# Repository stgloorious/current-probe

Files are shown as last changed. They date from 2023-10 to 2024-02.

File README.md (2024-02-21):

# Low-Noise Amplifier for Current Sensing

This is an experimental breakout board for the ultralow noise AD8331
variable-gain amplifier with internal low-noise preamplifier. 

- AC-coupled input up to 200 mV
- Adjustable gain amplifier, up to 55 dB
- Galvanically isolated output
- Single 3.3V supply

The input impedance of the amplifier should be around 6k ohms.
The probe is designed to be in close proximity (< 10 mm) to the signal source,
i.e., such that no shielded cable is required on the input side.
Instead, short wires can directly be soldered to the probe.
The output is matched to 50 ohms over an isolating signal transformer, which
connects to the SMA connector.

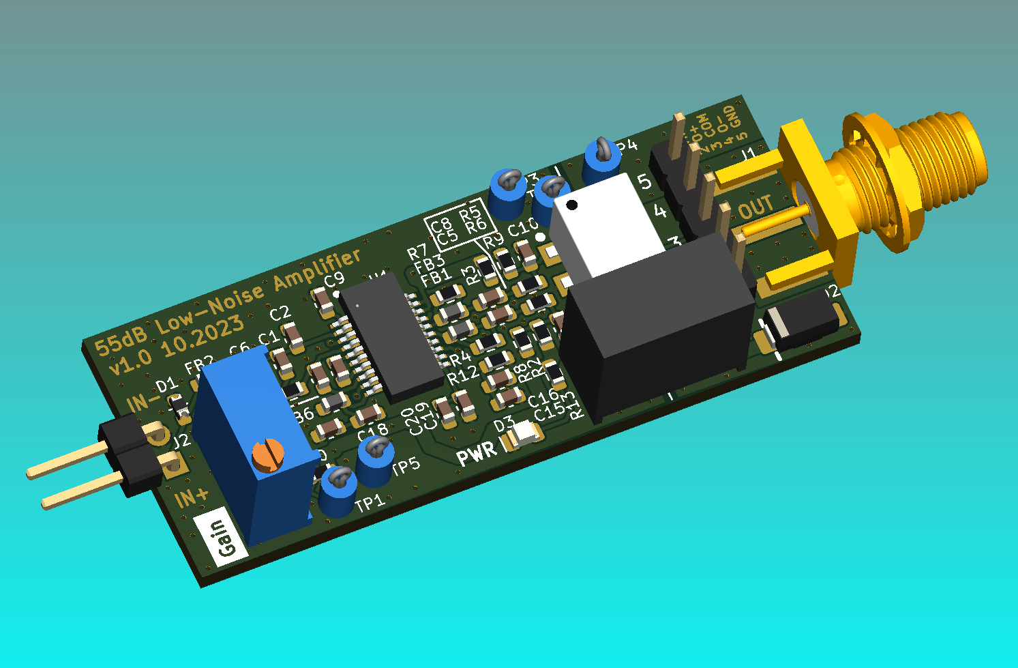
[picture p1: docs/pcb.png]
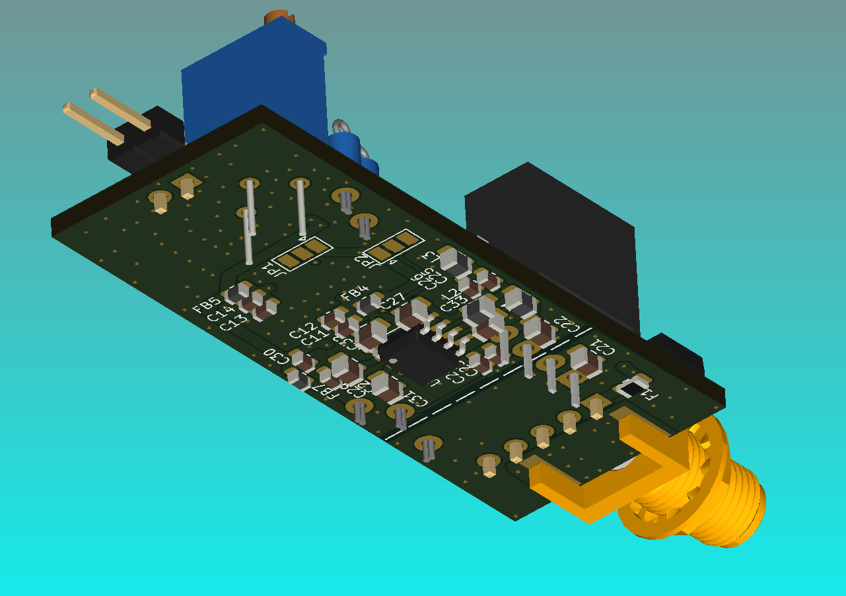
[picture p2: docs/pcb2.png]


The amplifier module is intended to be used as a current probe with
an additional shunt resistor. The amplifier is placed near the device 
under test and amplifies the voltage drop across the measurement resistor.
The output signal is digitized by an oscilloscope connected over the SMA connector.

## Progress

- [x] Schematics design
- [x] PCB layout
- [x] PCB prototype manufacturing
- [x] In-circuit verification
- [ ] Proof-of-concept of power analysis side channel attack

### Known Issues
Although there is a notch filter to suppress the parasitic switching frequency
of the DC/DC converter, it is still visible at the output.

## Motivation
The current probe is designed to measure the transient current consumption
of microcontrollers and low-end CPUs in order to use a power consumption
side channel, which can be used to leak information about cryptographic
operations.
An example power trace measured with this current probe can be seen below.
Clearly visible are the 10 AES rounds of the AES-128-ECB algorithm running
on an STM32 microcontroller.

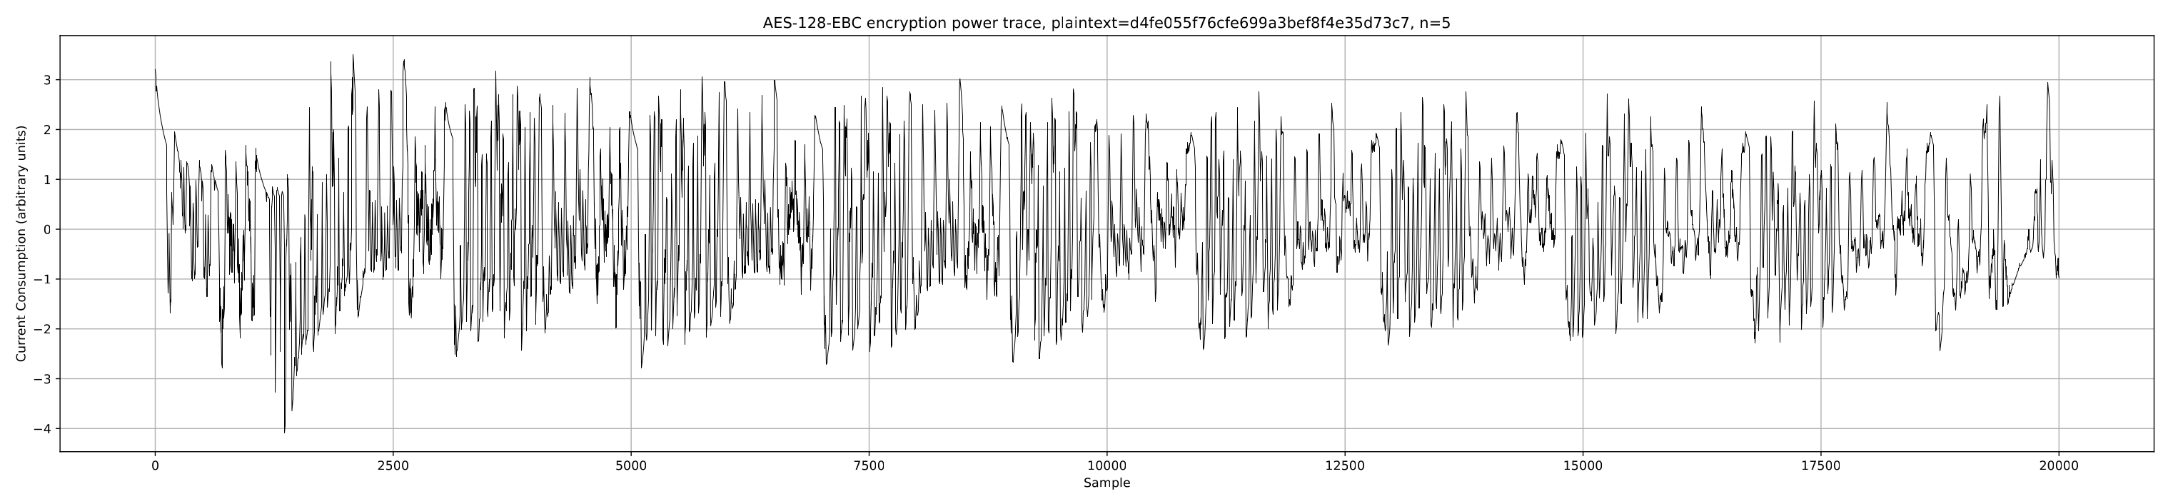
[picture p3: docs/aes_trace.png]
AES power trace


Such side-channel attacks have been known to exists for many years, and there
are even [commercial tools](https://chipwhisperer.readthedocs.io/en/latest/getting-started.html)
available which simplify the research process.

My goal with this DIY low-noise current probe is to have a cost-effective 
alternative to other specialized tools, as I already own 
suitable measurements equipment (i.e., an oscilloscope) 
and do not need access to other attack methods (such as fault injection).

## Manufacturing
PCB manufacturing was done in a custom panel with 5 individual PCBs by
[multi-cb](https://multi-cb.eu). Assembly was done by hand.

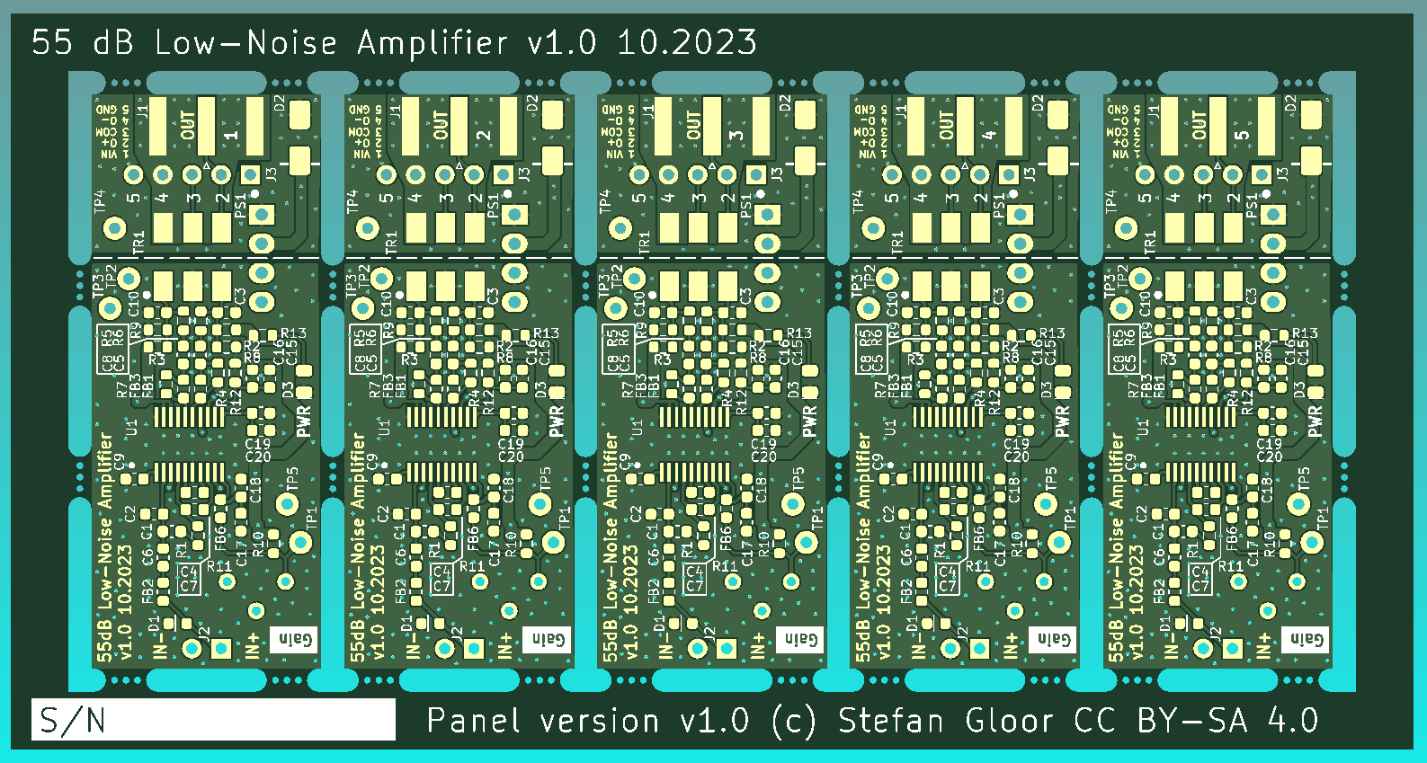
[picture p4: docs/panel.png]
panel

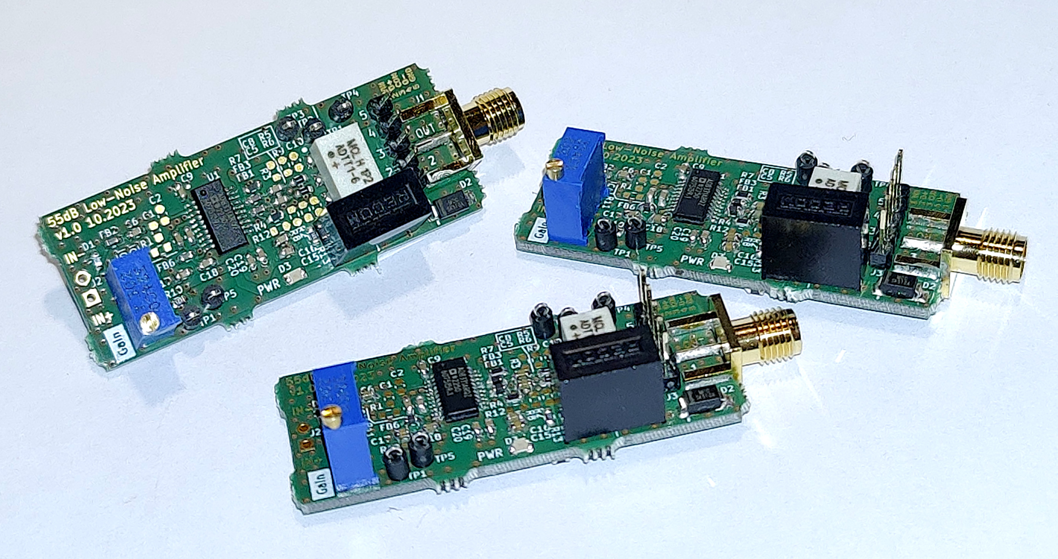
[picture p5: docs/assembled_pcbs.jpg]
pcbs


## License

<p xmlns:cc="http://creativecommons.org/ns#" xmlns:dct="http://purl.org/dc/terms/"><a property="dct:title" rel="cc:attributionURL" href="https://github.com/stgloorious/current-probe">current-probe</a> by <a rel="cc:attributionURL dct:creator" property="cc:attributionName" href="https://github.com/stgloorious/">Stefan Gloor</a> is licensed under <a href="http://creativecommons.org/licenses/by-sa/4.0/?ref=chooser-v1" target="_blank" rel="license noopener noreferrer" style="display:inline-block;">CC BY-SA 4.0</a></p>

This does not include work of third parties, e.g., 3D STEP models.

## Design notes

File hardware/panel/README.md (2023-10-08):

# Panel
This integrates 5 amplifier PCBs on a single panel.

panel

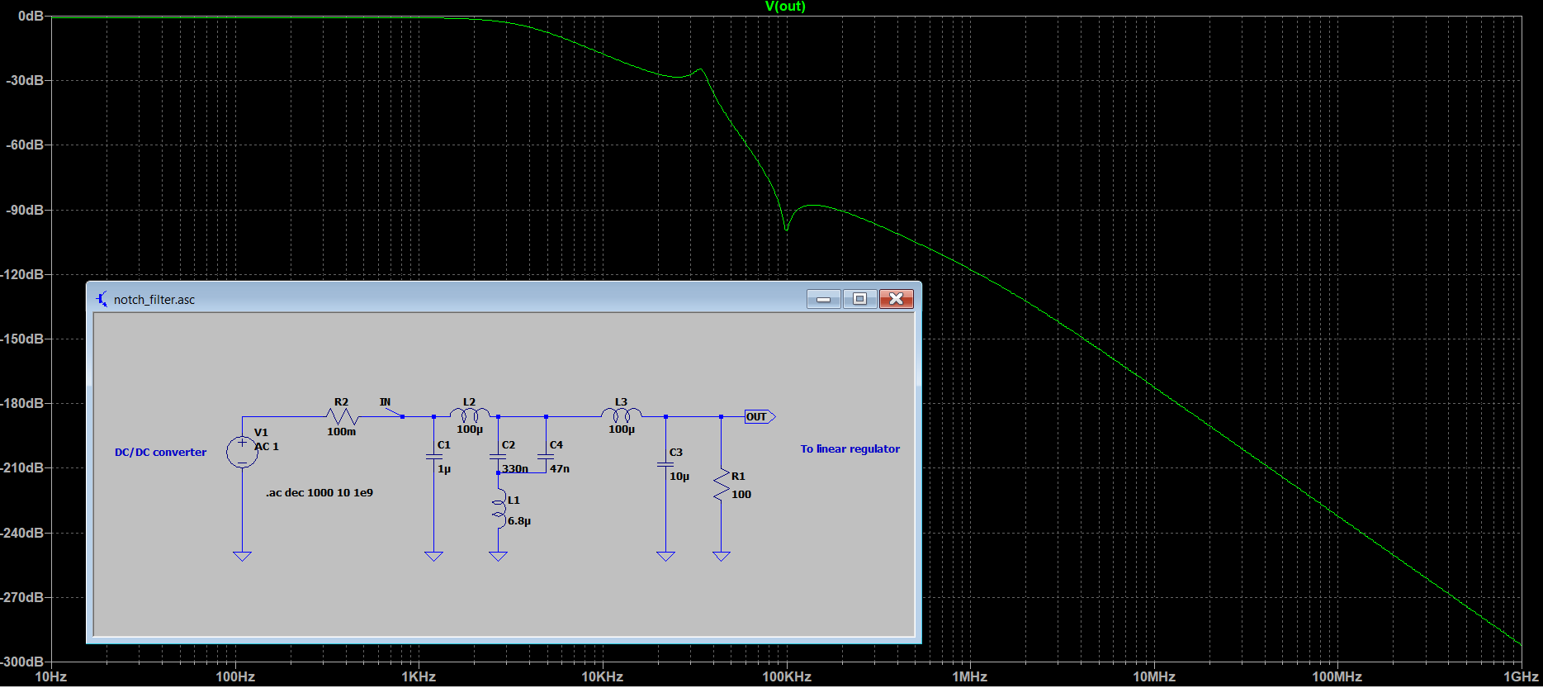
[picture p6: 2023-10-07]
sim/notch_filter.png

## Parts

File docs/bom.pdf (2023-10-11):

# Bill of Materials (BOM)

Project: current_probe
Version: 11.10.2023
Item Qty Designators | Value | Footprint | DNP | Part Number
1 | 1 | C1 | CFB | Capacitor_SMD:C_0603_1608Metric | DNP
2 | 1 | C2 | CSH | Capacitor_SMD:C_0603_1608Metric | DNP
3 | 2 | C3, C10 | 100p | Capacitor_SMD:C_0603_1608Metric | DNP
4 | 11 | C4, C5, C6, C7, C8, C9, C12, C14, C16, C18, C20 | 100n | Capacitor_SMD:C_0603_1608Metric | CL10B104KB8WPNC
5 | 8 | C11, C13, C15, C17, C19, C24, C29, C30 | 1n | Capacitor_SMD:C_0603_1608Metric | CL10B102KB8WPNC
6 | 4 | C21, C27, C28, C32 | 10u | Capacitor_SMD:C_0805_2012Metric | GCM21BR71A106KE22L
7 | 3 | C22, C31, C33 | 1u | Capacitor_SMD:C_0805_2012Metric | GCM21BR71H105MA03L
8 | 1 | C23 | 10n | Capacitor_SMD:C_0603_1608Metric | CL10B103KB8WPNC
9 | 1 | C25 | 330n | Capacitor_SMD:C_0603_1608Metric | CGA3E3X7R1H334K080AB
10 | 1 | C26 | 47n | Capacitor_SMD:C_0603_1608Metric | CGA3E2X7R1H473K080AA
11 | 1 | D1 | 2.5 pF | Diode_SMD:D_0603_1608Metric | GG0603052R542P
12 | 1 | D2 | D_Schottky | Diode_SMD:D_SMA | SK510A-LTP
13 | 1 | D3 | GREEN | LED_SMD:LED_0805_2012Metric | SML-LXT0805GW-TR
14 | 1 | F1 | 300 mA | Fuse:Fuse_0805_2012Metric | 0805L010/24YR
15 | 3 | FB1, FB2, FB3 | 22 | Inductor_SMD:L_0603_1608Metric | BLM18SD220SN1D
16 | 4 | FB4, FB5, FB6, FB7 | 2k2 | Inductor_SMD:L_0603_1608Metric | BLM18BD222SZ1D
17 | 1 | J1 | SMA | Connector_Coaxial:SMA_Amphenol_132289_EdgeMount | 132289RP
18 | 1 | J2 | Conn_01x02_Pin | Connector_PinHeader_2.54mm:PinHeader_1x02_P2.54mm_Horizontal | DNP
19 | 1 | J3 | Conn_01x05_Pin | Connector_PinHeader_2.54mm:PinHeader_1x05_P2.54mm_Vertical | 61300511121
20 | 2 | L1, L2 | 100u | Inductor_SMD:L_0805_2012Metric | MLZ2012N101LT000
21 | 1 | L3 | 6u8 | Inductor_SMD:L_0805_2012Metric | MLZ2012N6R8LT000
22 | 1 | PS1 | RO-3.309S | Converter_DCDC:Converter_DCDC_Murata_MEE1SxxxxSC_THT | RO-3.309S
23 | 1 | R1 | RFB | Resistor_SMD:R_0603_1608Metric | DNP
24 | 4 | R2, R3, R8, R9 | R | Resistor_SMD:R_0603_1608Metric | DNP
25 | 2 | R4, R7 | 100 | Resistor_SMD:R_0603_1608Metric | RS73F1JTTD1000B
26 | 2 | R5, R6 | 237 | Resistor_SMD:R_0603_1608Metric | ERJ-PB3B2370V
27 | 1 | R10 | 12k | Resistor_SMD:R_0603_1608Metric | AC0603FR-0712KL
28 | 1 | R11 | 3k | Potentiometer_THT:Potentiometer_Bourns_3296Y_Vertical | 3296Y-1-302LF
29 | 1 | R12 | RCLMP | Resistor_SMD:R_0603_1608Metric | DNP
30 | 1 | R13 | 330 | Resistor_SMD:R_0603_1608Metric | RMCF0603FT330R
31 | 5 | TP1, TP2, TP3, TP4, TP5 | TestPoint | TestPoint:TestPoint_Loop_D1.80mm_Drill1.0mm_Beaded | 5001
32 | 1 | TR1 | ADTT1-6+ | RF_Mini-Circuits:Mini-Circuits_CD637_H5.23mm | ADTT1-6+
33 | 1 | U1 | AD8331ARQZ | current_probe:RQ_20_ADI-L | AD8331ARQZ
34 | 1 | U2 | ADM7150ARDZ-5.0 | Package_SO:SOIC-8-1EP_3.9x4.9mm_P1.27mm_EP2.29x3mm | ADM7150ARDZ-5.0

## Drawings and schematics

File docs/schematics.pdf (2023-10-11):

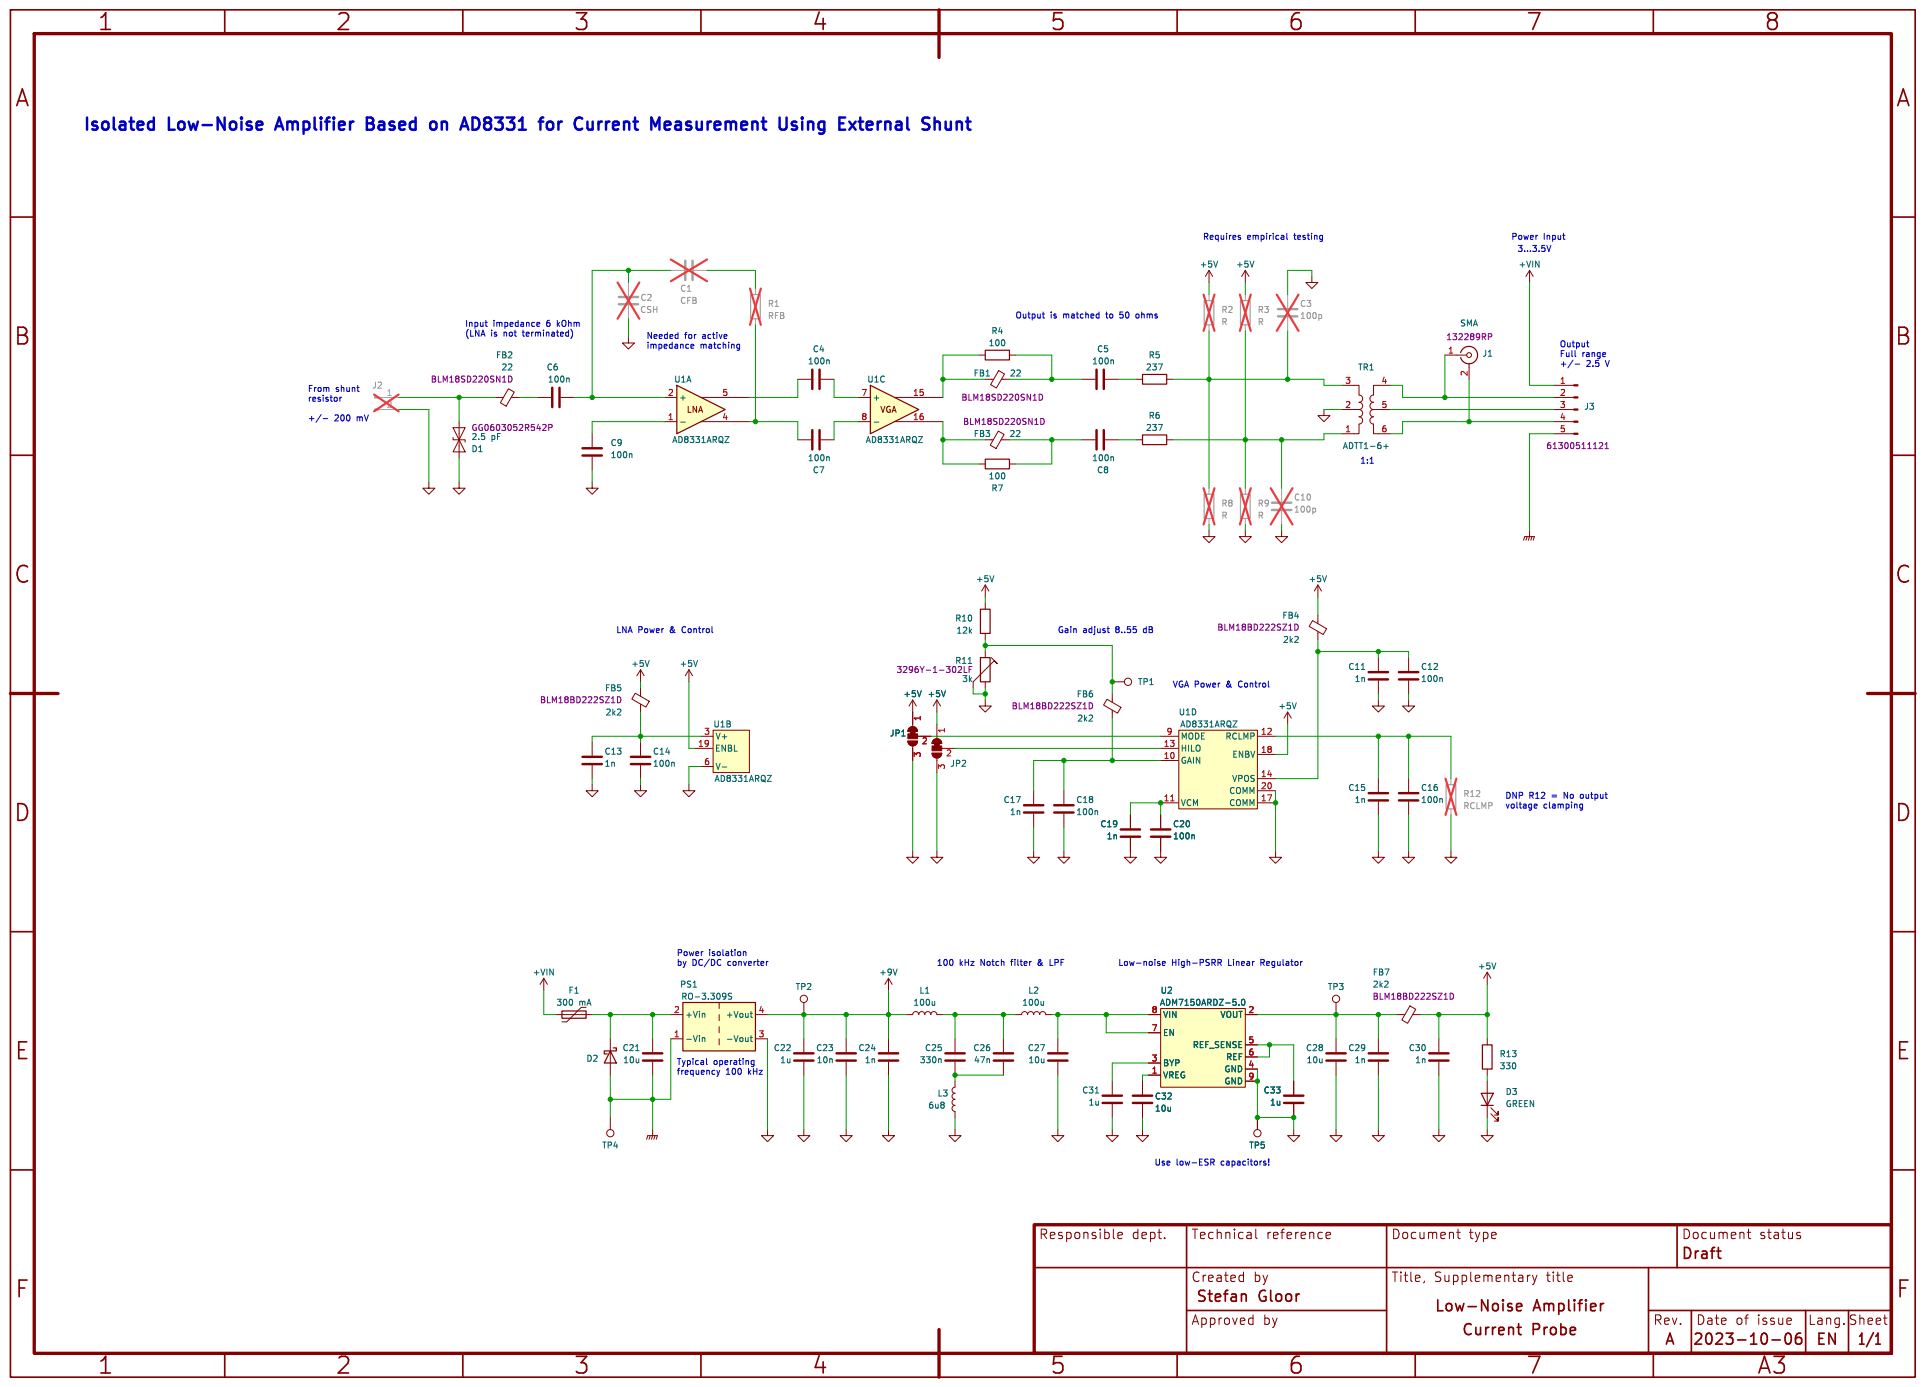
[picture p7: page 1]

100 kHz Notch filter & LPF

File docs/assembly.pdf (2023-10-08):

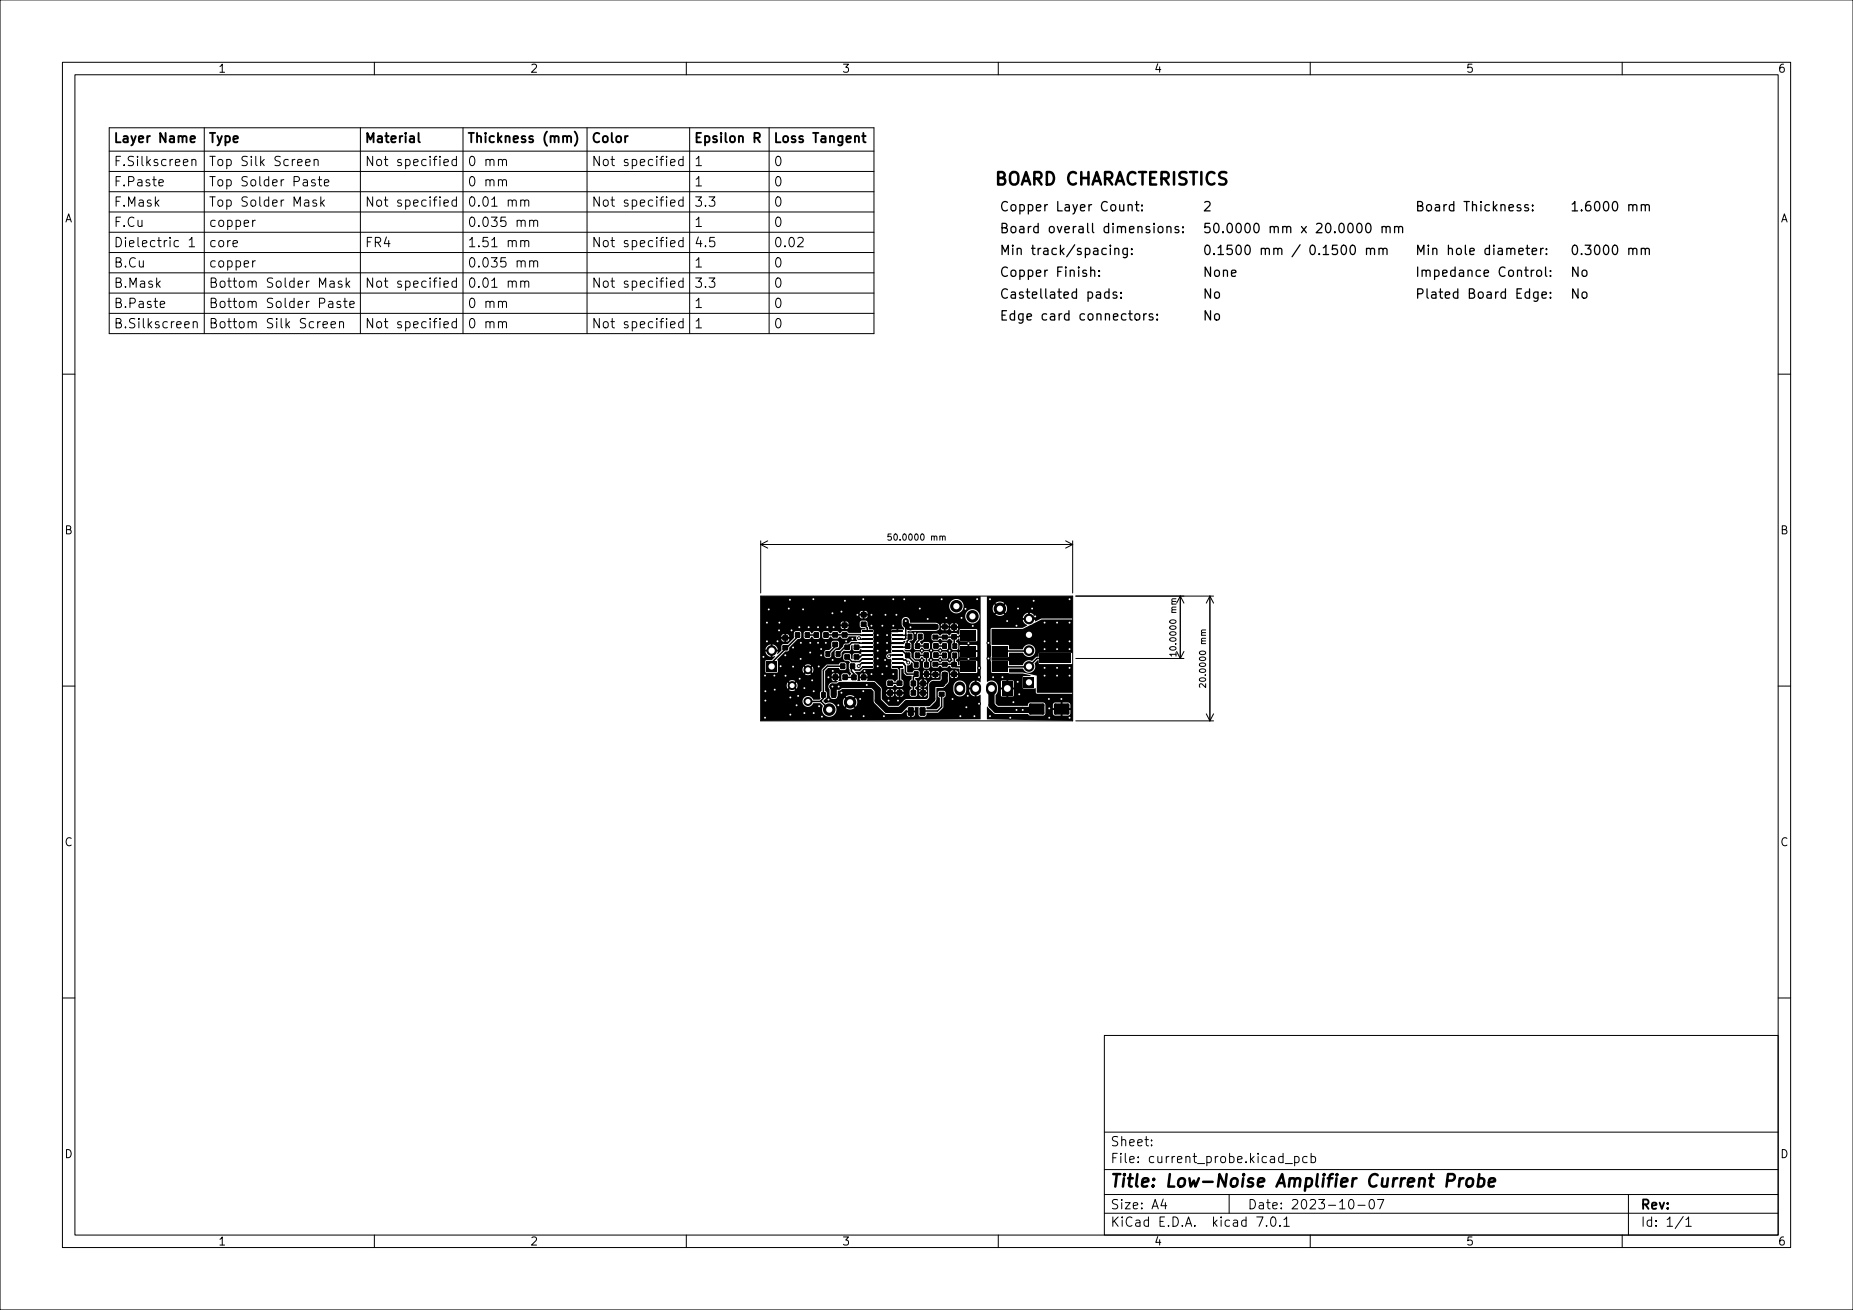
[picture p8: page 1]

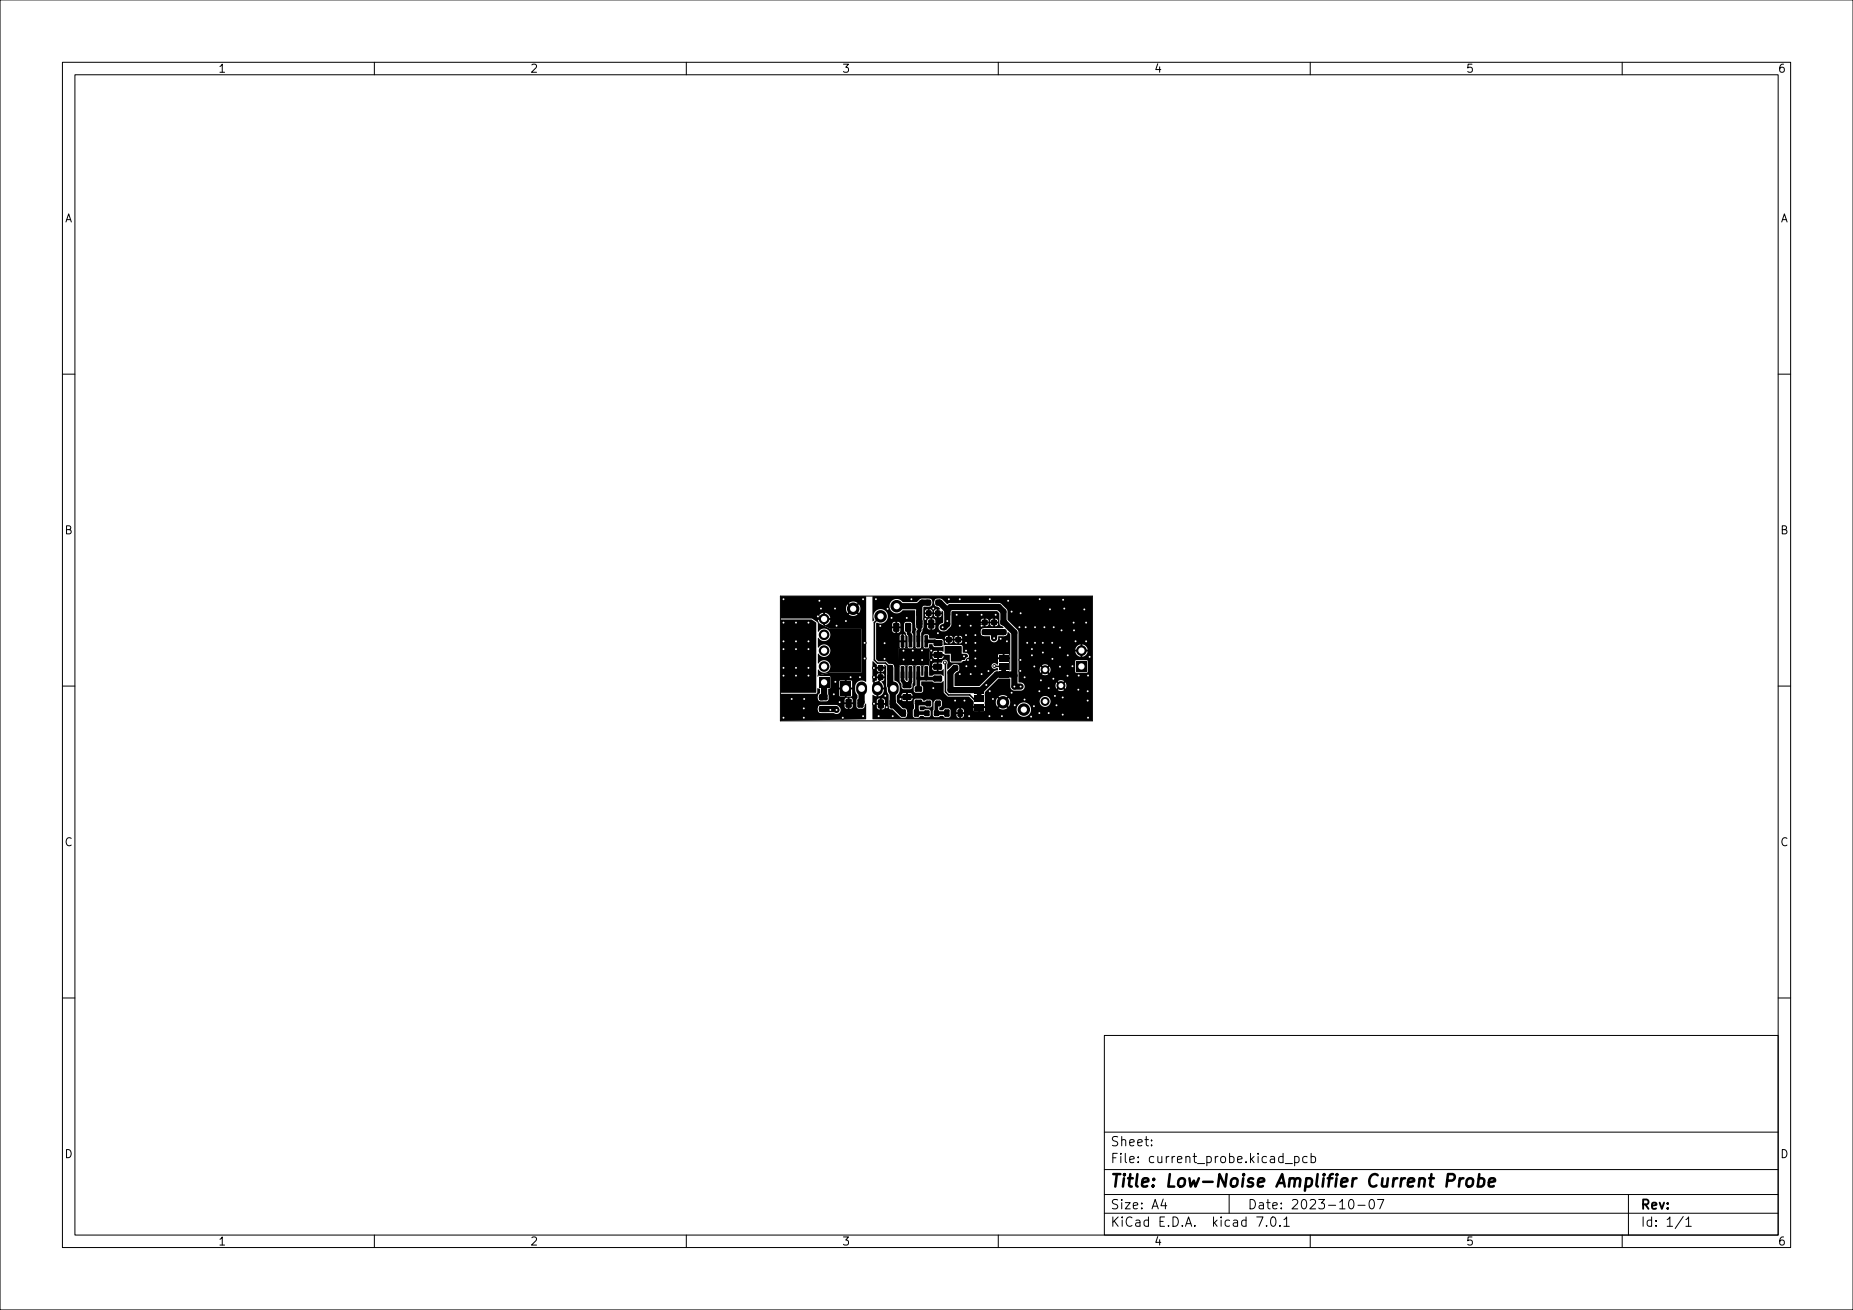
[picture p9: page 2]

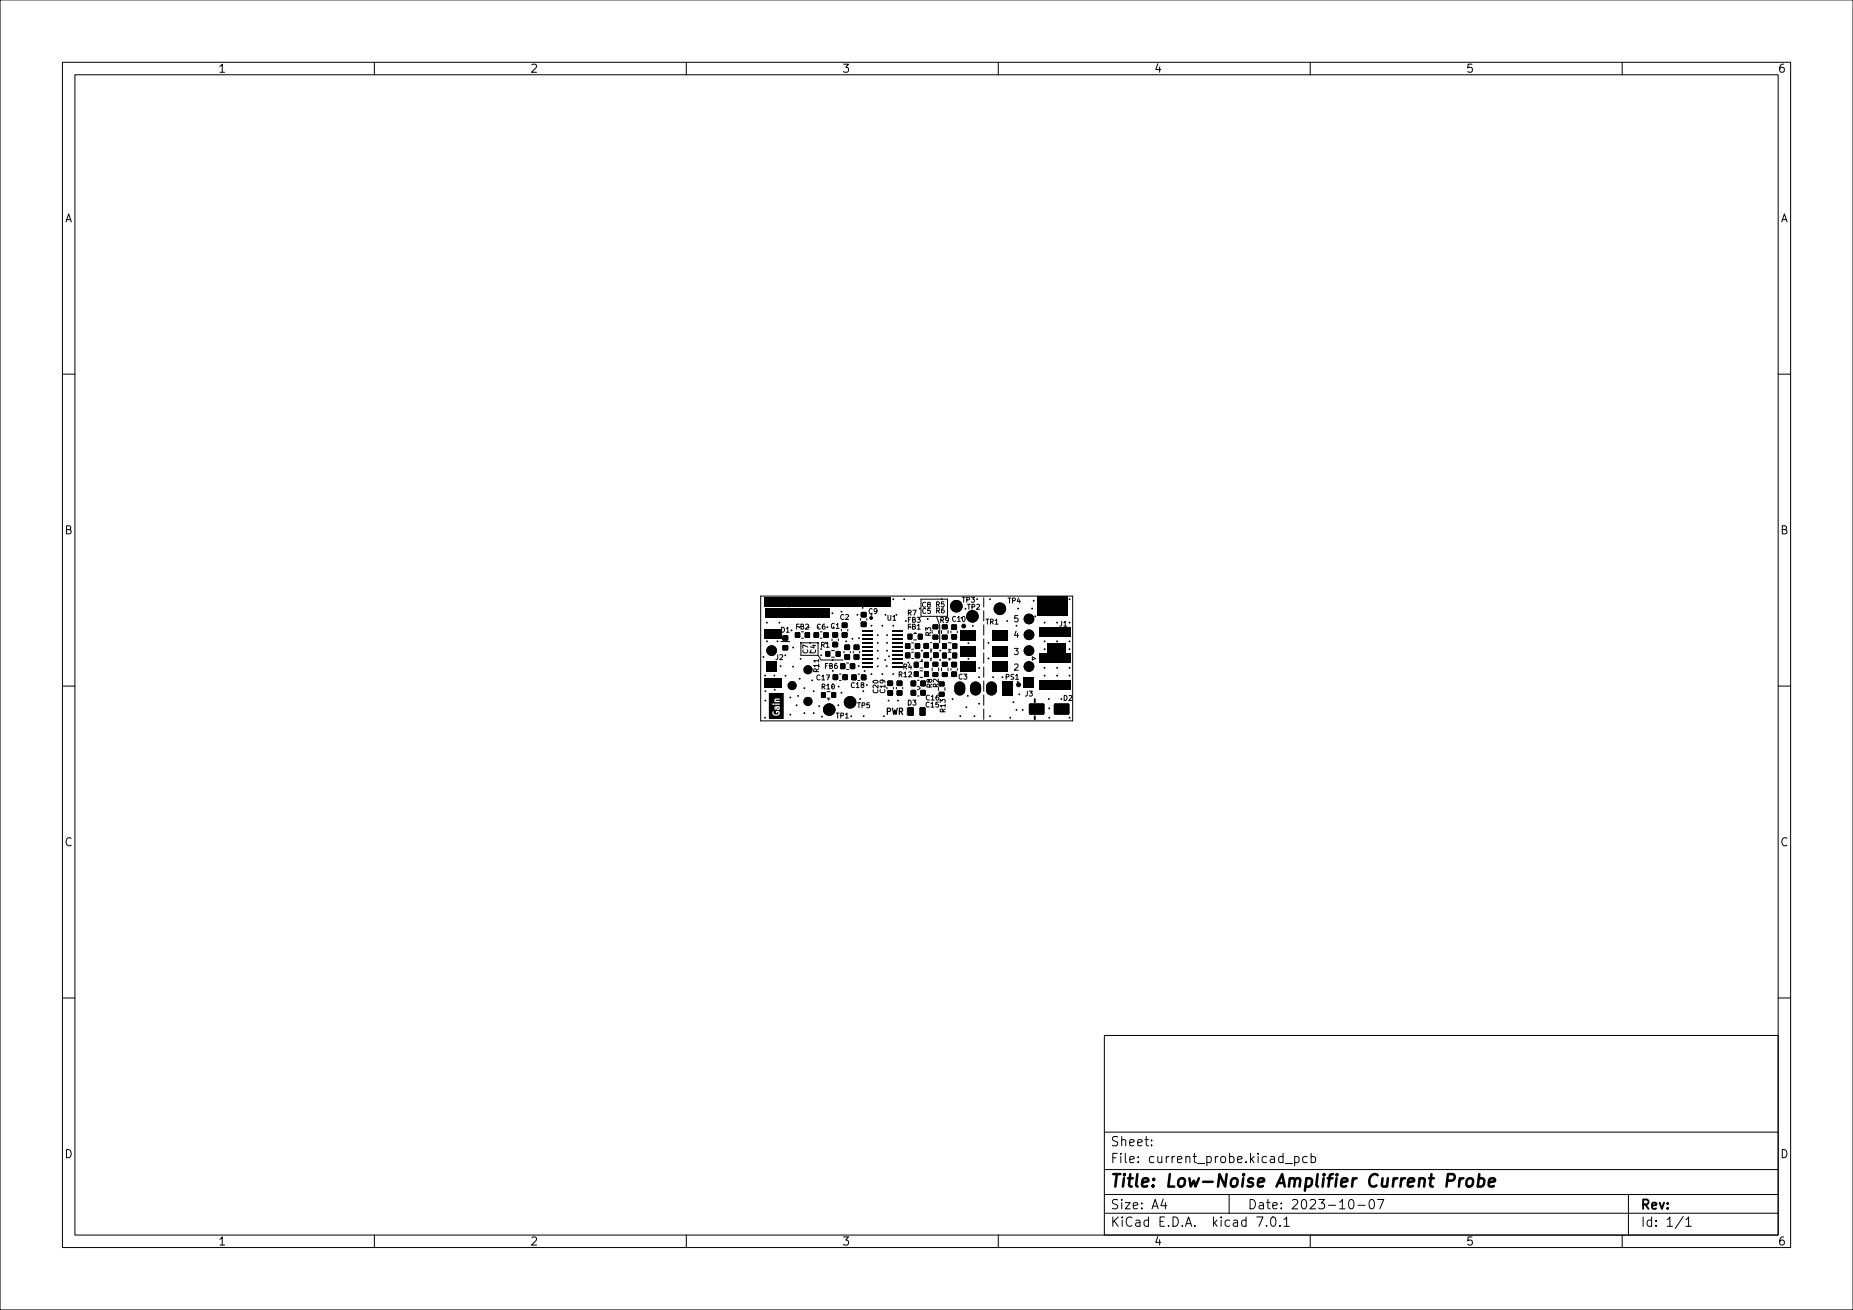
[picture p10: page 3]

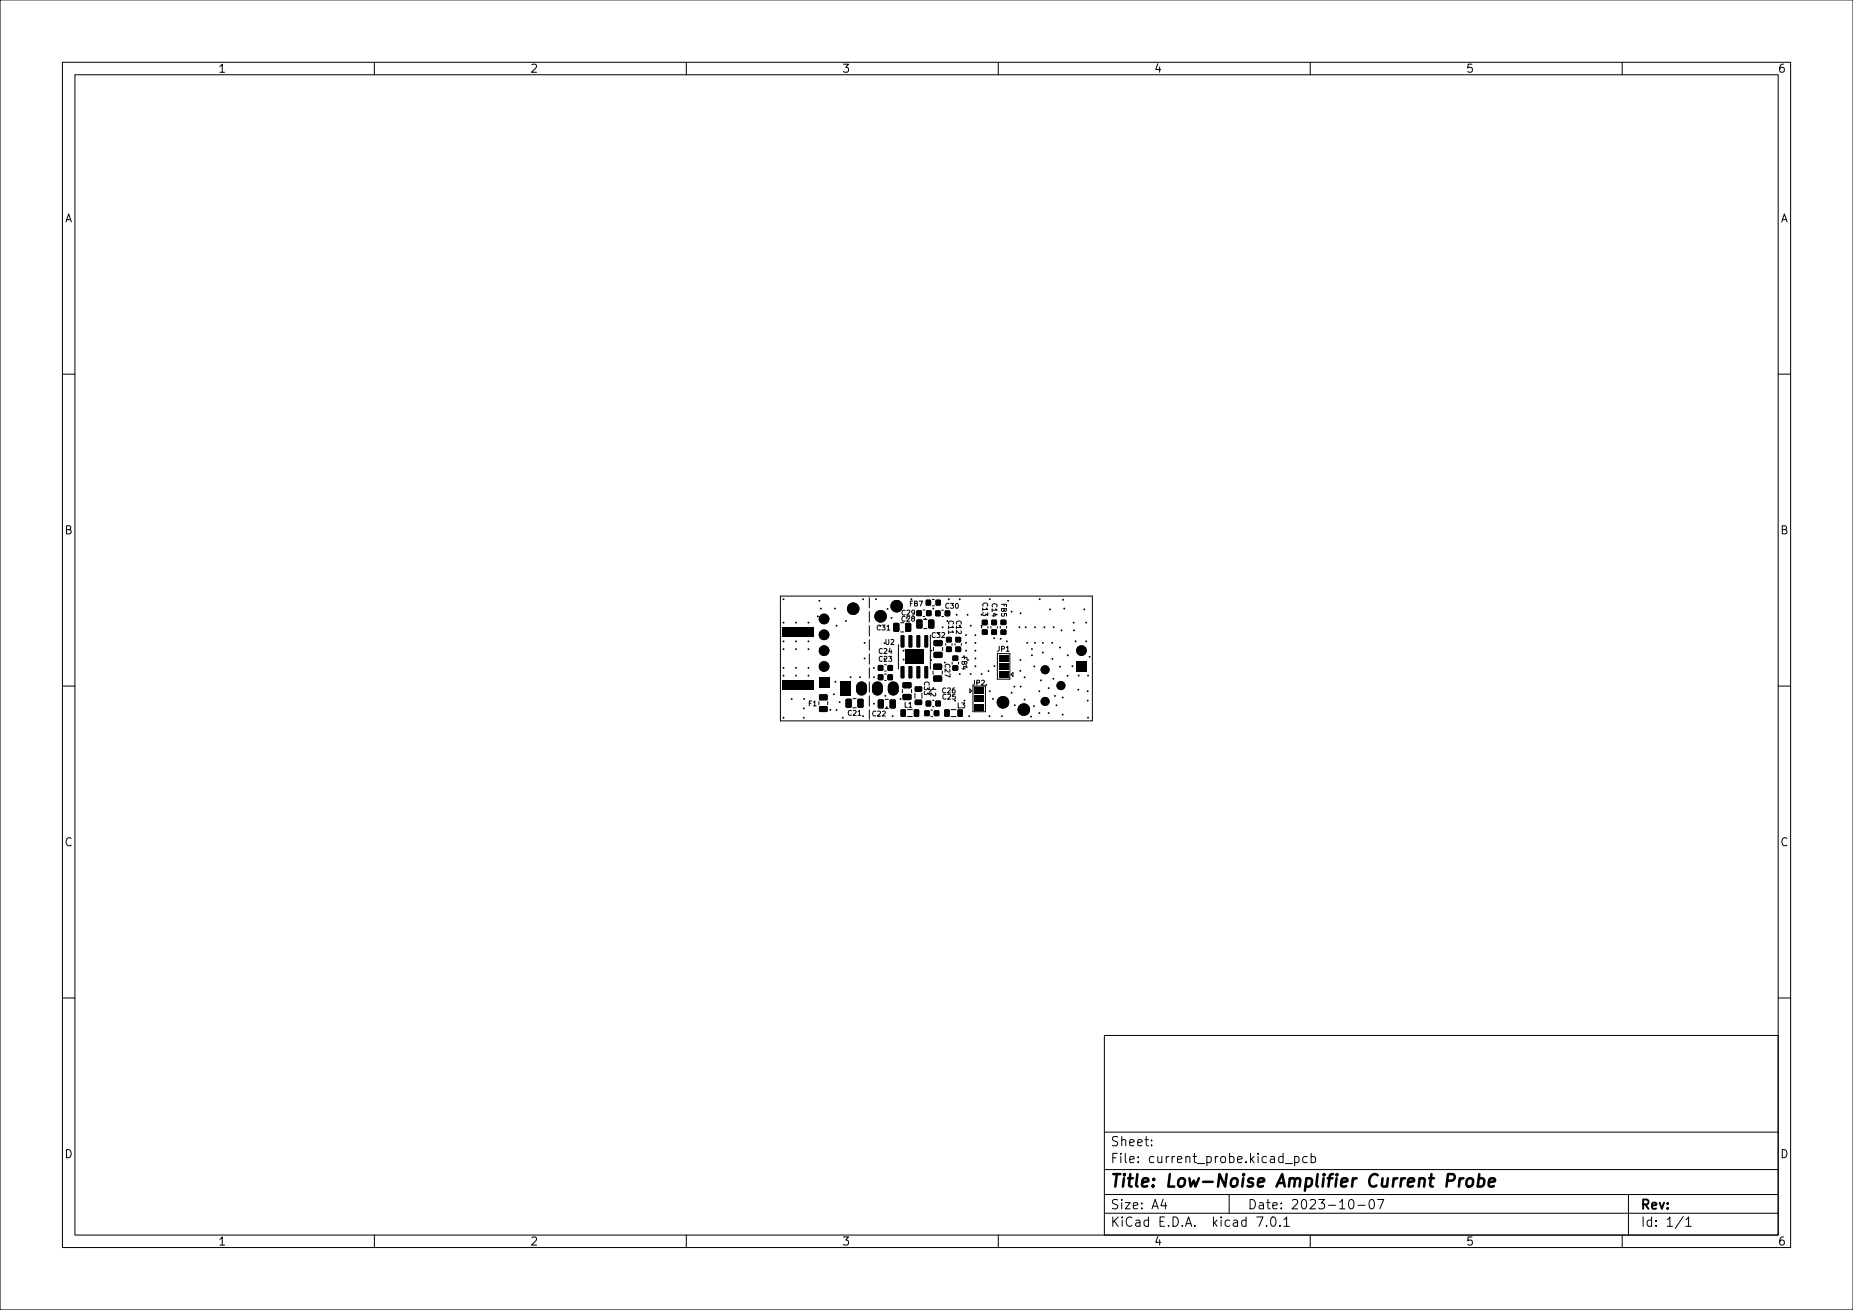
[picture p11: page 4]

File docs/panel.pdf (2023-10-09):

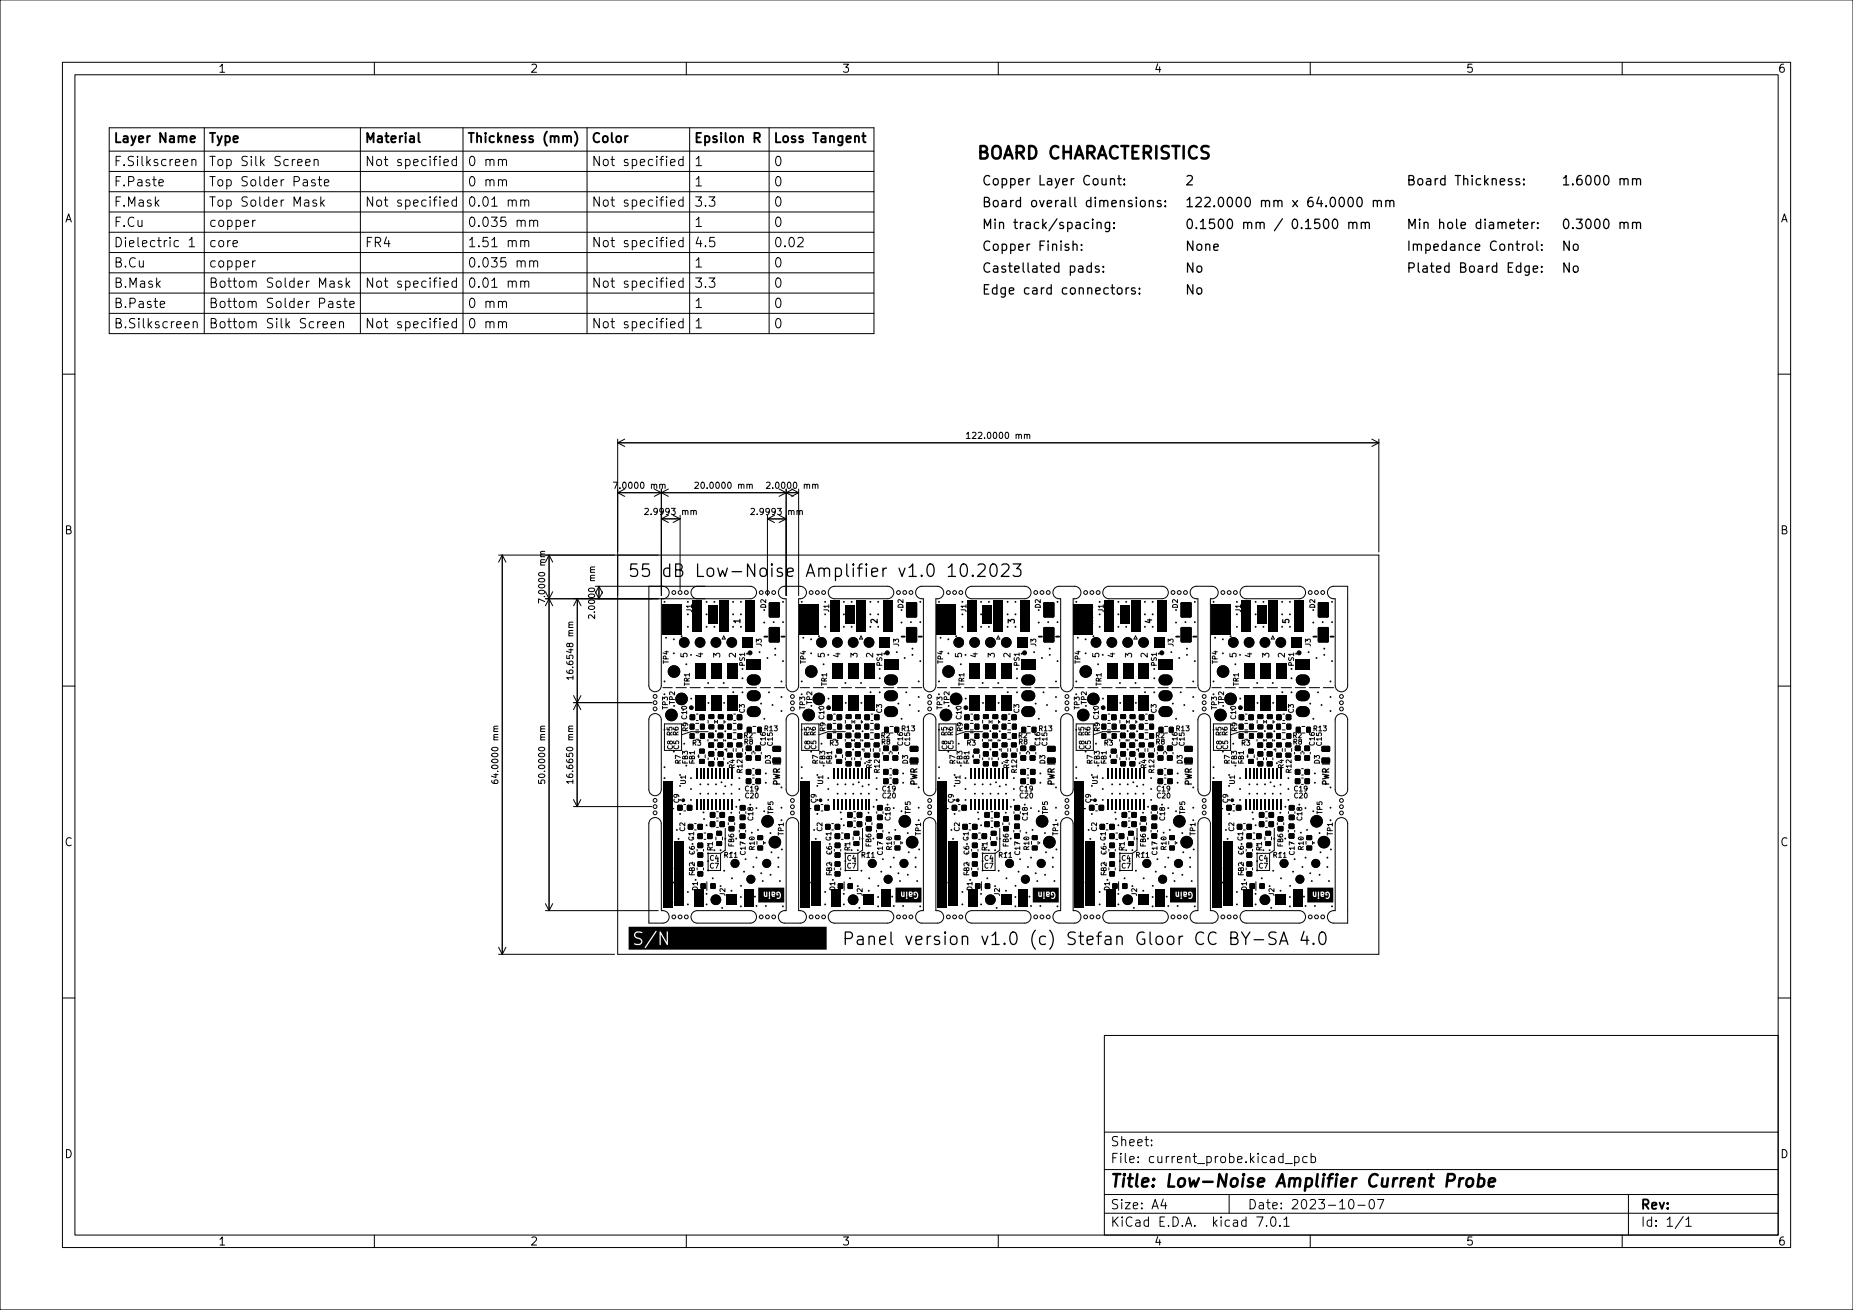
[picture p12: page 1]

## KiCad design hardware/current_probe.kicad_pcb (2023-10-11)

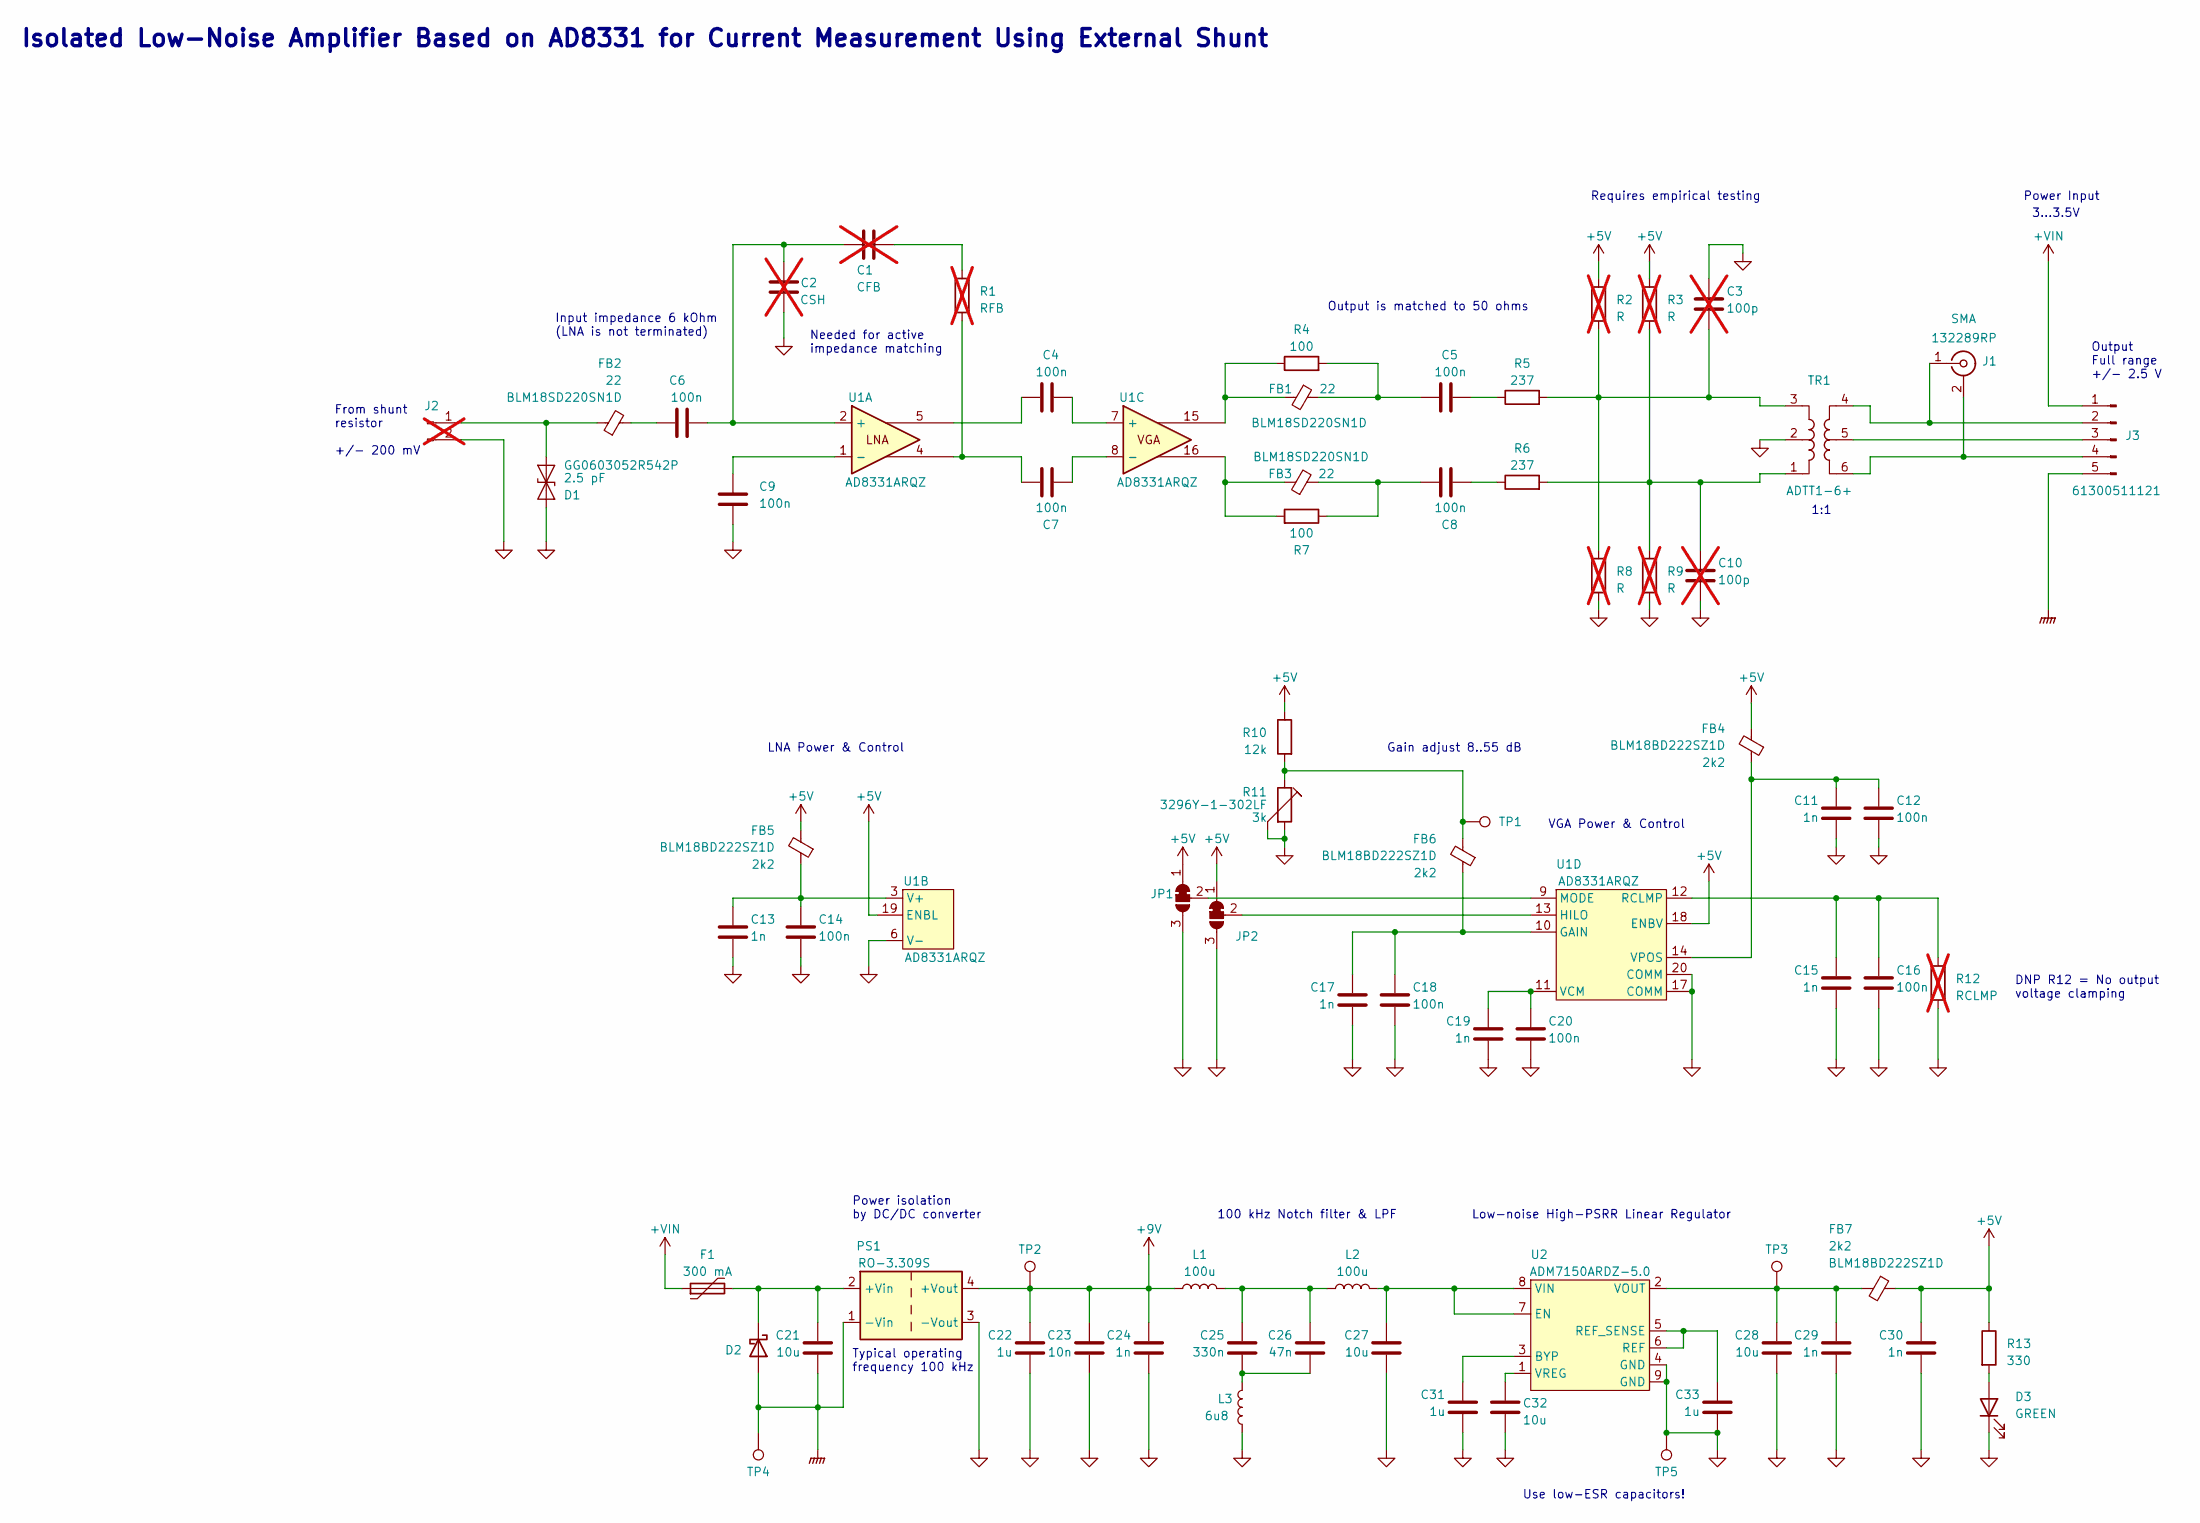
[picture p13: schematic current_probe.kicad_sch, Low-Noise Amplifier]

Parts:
C1: CFB; C_0603_1608Metric; not fitted
C2: CSH; C_0603_1608Metric; not fitted
C3, C10: 100p; C_0603_1608Metric; not fitted
C4, C5, C6, C7, C8, C9, C12, C14, C16, C18, C20: 100n; C_0603_1608Metric; Part CL10B104KB8WPNC
C11, C13, C15, C17, C19, C29, C30: 1n; C_0603_1608Metric; Part CL10B102KB8WPNC
C21, C27, C28, C32: 10u; C_0805_2012Metric; Part GCM21BR71A106KE22L
C22, C31, C33: 1u; C_0805_2012Metric; Part GCM21BR71H105MA03L
C23: 10n; C_0603_1608Metric; Part CL10B103KB8WPNC
C24: 1n; C_0603_1608Metric
C25: 330n; C_0603_1608Metric; Part CGA3E3X7R1H334K080AB
C26: 47n; C_0603_1608Metric; Part CGA3E2X7R1H473K080AA
D1: 2.5 pF; D_0603_1608Metric; Part GG0603052R542P
D2: D_Schottky; D_SMA; Part SK510A-LTP
D3: GREEN; LED_0805_2012Metric; Part SML-LXT0805GW-TR
F1: 300 mA; Fuse_0805_2012Metric; Part 0805L010/24YR
FB1, FB2, FB3: 22; L_0603_1608Metric; Part BLM18SD220SN1D
FB4, FB5, FB6, FB7: 2k2; L_0603_1608Metric; Part BLM18BD222SZ1D
J1: SMA; SMA_Amphenol_132289_EdgeMount; Part 132289RP
J2: Conn_01x02_Pin; PinHeader_1x02_P2.54mm_Horizontal; not fitted
J3: Conn_01x05_Pin; PinHeader_1x05_P2.54mm_Vertical; Part 61300511121
JP1, JP2: SolderJumper_3_Bridged12; SolderJumper-3_P1.3mm_Bridged12_Pad1.0x1.5mm
L1, L2: 100u; L_0805_2012Metric; Part MLZ2012N101LT000
L3: 6u8; L_0805_2012Metric; Part MLZ2012N6R8LT000
PS1: RO-3.309S; Converter_DCDC_Murata_MEE1SxxxxSC_THT; Part RO-3.309S
R1: RFB; R_0603_1608Metric; not fitted
R2, R3, R8, R9: R; R_0603_1608Metric; not fitted
R4, R7: 100; R_0603_1608Metric; Part RS73F1JTTD1000B
R5, R6: 237; R_0603_1608Metric; Part ERJ-PB3B2370V
R10: 12k; R_0603_1608Metric; Part AC0603FR-0712KL
R11: 3k; Potentiometer_Bourns_3296Y_Vertical; Part 3296Y-1-302LF
R12: RCLMP; R_0603_1608Metric; not fitted
R13: 330; R_0603_1608Metric; Part RMCF0603FT330R
TP1, TP2, TP3, TP4, TP5: TestPoint; TestPoint_Loop_D1.80mm_Drill1.0mm_Beaded; Part 5001
TR1: ADTT1-6+; Mini-Circuits_CD637_H5.23mm; Part ADTT1-6+
U1: AD8331ARQZ; RQ_20_ADI-L; Part AD8331ARQZ
U2: ADM7150ARDZ-5.0; SOIC-8-1EP_3.9x4.9mm_P1.27mm_EP2.29x3mm; Part ADM7150ARDZ-5.0

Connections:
+5V: C30.2, FB4.2, FB5.2, FB7.1, JP1.1 (A), JP2.1 (A), R2.1, R3.1, R10.1, R13.1, U1.18 (ENBV), U1.19 (ENBL)
+9V: C22.2, C23.2, C24.2, L1.1, PS1.4 (+Vout), TP2.1
+VIN: F1.1, J3.1
GND: C2.2, C3.2, C9.2, C10.1, C11.1, C12.1, C13.1, C14.1, C15.1, C16.1, C17.1, C18.1, C19.1, C20.1, C22.1, C23.1, C24.1, C27.1, C28.1, C29.1, C30.1, C31.1, C32.1, C33.1, D1.2 (A2), D3.1 (K), J2.2, JP1.3 (B), JP2.3 (B), L3.1, PS1.3 (-Vout), R8.2, R9.2, R11.2, R11.3, R12.2, TP5.1, TR1.2, U1.6 (V-), U1.17 (COMM), U1.20 (COMM), U2.4 (GND), U2.9 (GND)
GNDPWR: C21.1, D2.2 (A), J3.5, PS1.1 (-Vin), TP4.1
unnamed: C1.2, R1.1
unnamed: C3.1, R2.2, R5.2, R8.1, TR1.3
unnamed: C4.2, U1.5
unnamed: C5.1, R5.1
unnamed: C5.2, FB1.1, R4.2
unnamed: C6.2, FB2.2
unnamed: C7.2, R1.2, U1.4
unnamed: C8.1, R6.1
unnamed: C8.2, FB3.2, R7.1
unnamed: C10.2, R3.2, R6.2, R9.1, TR1.1
unnamed: C25.1, C26.1, L3.2
unnamed: C25.2, C26.2, L1.2, L2.1
unnamed: D1.1 (A1), FB2.1, J2.1
unnamed: C21.2, D2.1 (K), F1.2, PS1.2 (+Vin)
unnamed: D3.2 (A), R13.2
unnamed: FB1.2, R4.1, U1.15
unnamed: FB3.1, R7.2, U1.16
unnamed: FB6.2, R10.2, R11.1, TP1.1
unnamed: J1.2 (Ext), J3.4, TR1.6
unnamed: J1.1 (In), J3.2, TR1.4
unnamed: J3.3, TR1.5
unnamed: JP1.2 (C), U1.9 (MODE)
unnamed: JP2.2 (C), U1.13 (HILO)
unnamed: C1.1, C2.1, C6.1, U1.2 (+)
unnamed: C9.1, U1.1 (-)
unnamed: C13.2, C14.2, FB5.1, U1.3 (V+)
unnamed: C4.1, U1.7 (+)
unnamed: C7.1, U1.8 (-)
unnamed: C17.2, C18.2, FB6.1, U1.10 (GAIN)
unnamed: C15.2, C16.2, R12.1, U1.12 (RCLMP)
unnamed: C19.2, C20.2, U1.11 (VCM)
unnamed: C11.2, C12.2, FB4.1, U1.14 (VPOS)
unnamed: C31.2, U2.3 (BYP)
unnamed: C27.2, L2.2, U2.7 (EN), U2.8 (VIN)
unnamed: C33.2, U2.5 (REF_SENSE), U2.6 (REF)
unnamed: C28.2, C29.2, FB7.2, TP3.1, U2.2 (VOUT)
unnamed: C32.2, U2.1 (VREG)

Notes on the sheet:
100 kHz Notch filter & LPF
From shunt resistor +/- 200 mV
LNA Power & Control
1:1
Power Input
Output Full range +/- 2.5 V
3...3.5V
DNP R12 = No output voltage clamping
Output is matched to 50 ohms
VGA Power & Control
Needed for active impedance matching
Use low-ESR capacitors!
Typical operating frequency 100 kHz
Low-noise High-PSRR Linear Regulator
Input impedance 6 kOhm (LNA is not terminated)
Gain adjust 8..55 dB
Isolated Low-Noise Amplifier Based on AD8331 for Current Measurement Using External Shunt
Requires empirical testing
Power isolation by DC/DC converter

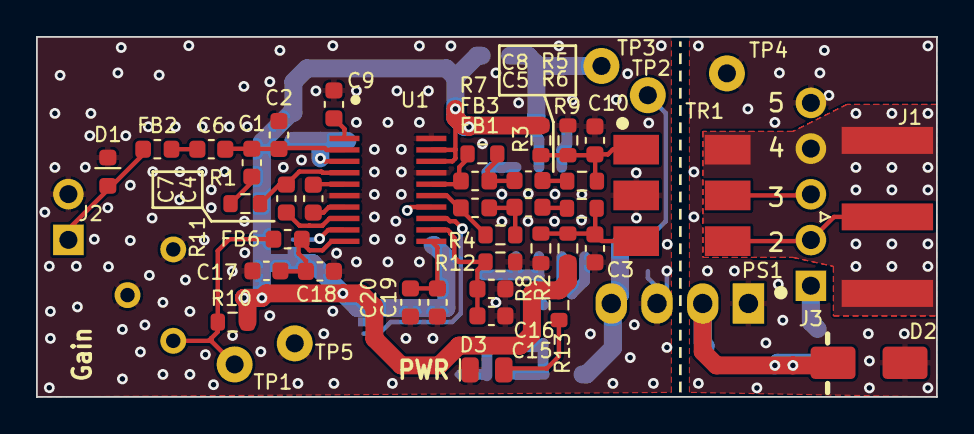
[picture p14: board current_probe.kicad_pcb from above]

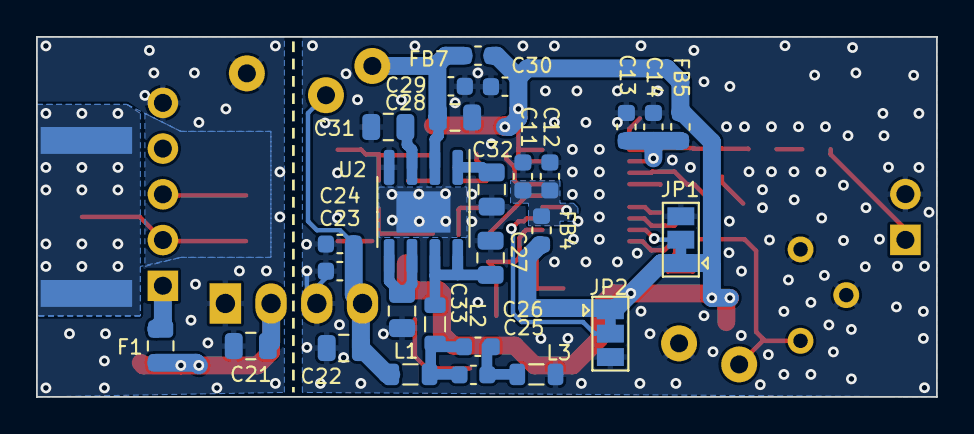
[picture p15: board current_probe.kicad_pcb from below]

Board: 2 copper layers, 50.0 x 20.0 mm, 74 parts (27 on the bottom side), 42 nets.

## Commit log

2023-10-07 Add simulations - LTspice simulation of Notch Filter and Low pass filter used inbetween DC/DC converter and linear regulator.
2023-10-07 Add hardware files
    [current_probe.kicad_pcb, current_probe.kicad_sch]
2023-10-07 Add docs
    [bom.xlsx]
2023-10-07 Consolidate layer and assembly drawings into a single file
2023-10-08 Incorporate design review feedback - Enhance routing of input path - Remove voltage reference, used voltage divider instead for gain voltage - Made vias smaller
    [bom.xlsx, current_probe.kicad_pcb, current_probe.kicad_sch]
2023-10-08 Create panel - Create panel design with 5 amplifier PCBs - Add panel assembly drawing - Add production data
    [current_probe-B_Cu.gbl, current_probe-B_Mask.gbs, current_probe-B_Paste.gbp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]
2023-10-08 Add unit numbers to panel
    [current_probe-B_Cu.gbl, current_probe-B_Mask.gbs, current_probe-B_Paste.gbp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]
2023-10-09 Tried to fix edge cuts and via sizes in panel, regenerated gerbers
    [current_probe-B_Cu.gbl, current_probe-B_Mask.gbs, current_probe-B_Paste.gbp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]
2023-10-09 Fix edge cuts on panel
    [current_probe-B_Cu.gbl, current_probe-B_Mask.gbs, current_probe-B_Paste.gbp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]
2023-10-11 Updated BOM and part numbers
    [bom.xlsx, current_probe.kicad_pcb, current_probe.kicad_sch]
2023-10-20 PCB assembly - updated progress - add picture
2024-02-21 Add power trace and update progress; add known issues

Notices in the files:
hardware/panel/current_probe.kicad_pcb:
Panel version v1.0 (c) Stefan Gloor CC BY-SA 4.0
